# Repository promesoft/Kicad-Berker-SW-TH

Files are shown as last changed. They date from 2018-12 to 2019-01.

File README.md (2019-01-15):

Green board

# Overview
## Status - Rev A - Functional with issues
Rev A done by PCBWay

## Wemos D1 mini - section 1

Section 1 is a sensor board for a Wemos D1 mini, that is intended for installing in a Berker wall outlet (euro style). 
Section 1 has an AM2320, a relay and a power supply. Besides this it has breakout of pins A0 and D4.

## Issues

There is one issue with section 1 that should be addressed in the next revision. The board size is 2mm too big in X and Y, to fit into a Berker wall mount. 

## Errata
 - Edgecuts in Rev A is specified as 0,15mm - this should be 1mm
 - Footprint for AC-DC is wrong
 - Footprint for Q3 and Q4 is off

## Wemos D1 mini - section 2

Section 2 is similar to section 1 except it has room on the backside for a PM03 AC-DC converter. 
It is intended as a board for installing in a Berker outlet. 
Section 2 has an AM2320, a relay and a power supply. Besides this it has breakout of pins A0 and D4.

## Issues

There are two flaws with section 2 that should be addressed in the next revision: 
### Board dimensions
The corners of the board inhibits it from fitting into a Berker wall mount. 
Either the board should be 47x47mm (3mm shorter in X and Y) or the corners should be milled away with a 8mm diameter drill
### Footprint of AC-DC converter
The PM03 footprint has been flipped so it does not fit in the PCB.

## Virtual Ground Section

# 3D board view

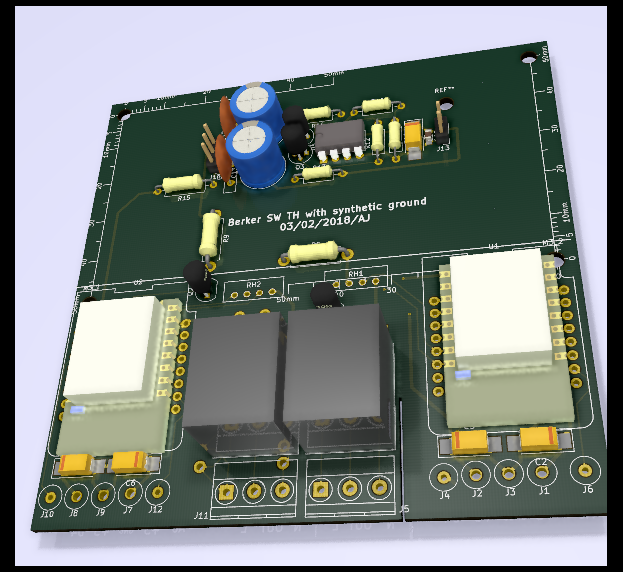
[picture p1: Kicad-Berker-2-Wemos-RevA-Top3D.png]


# Shecmatic

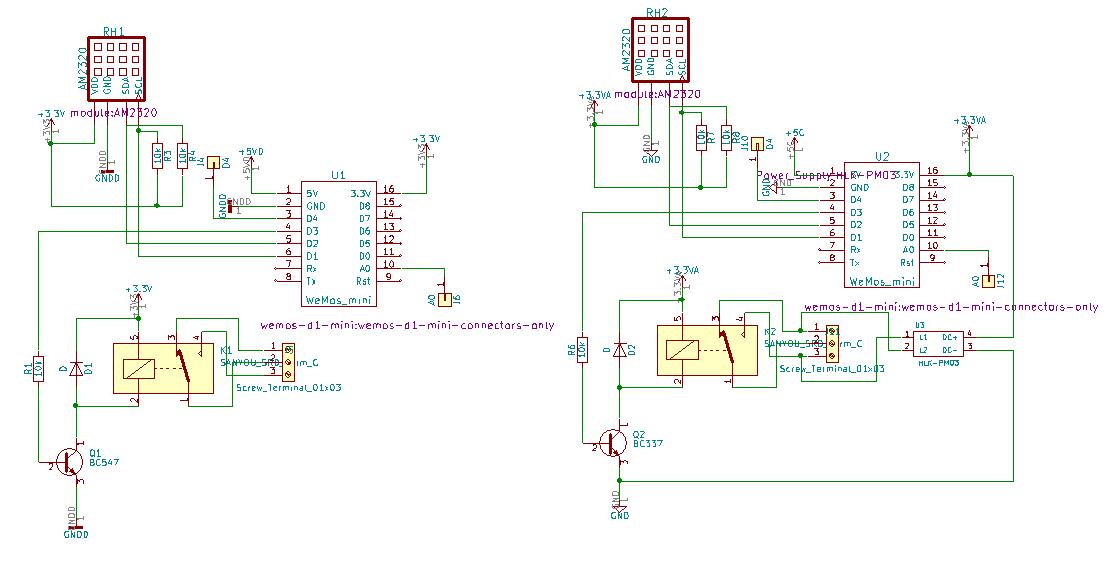
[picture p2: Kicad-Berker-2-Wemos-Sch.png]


# Section 2 
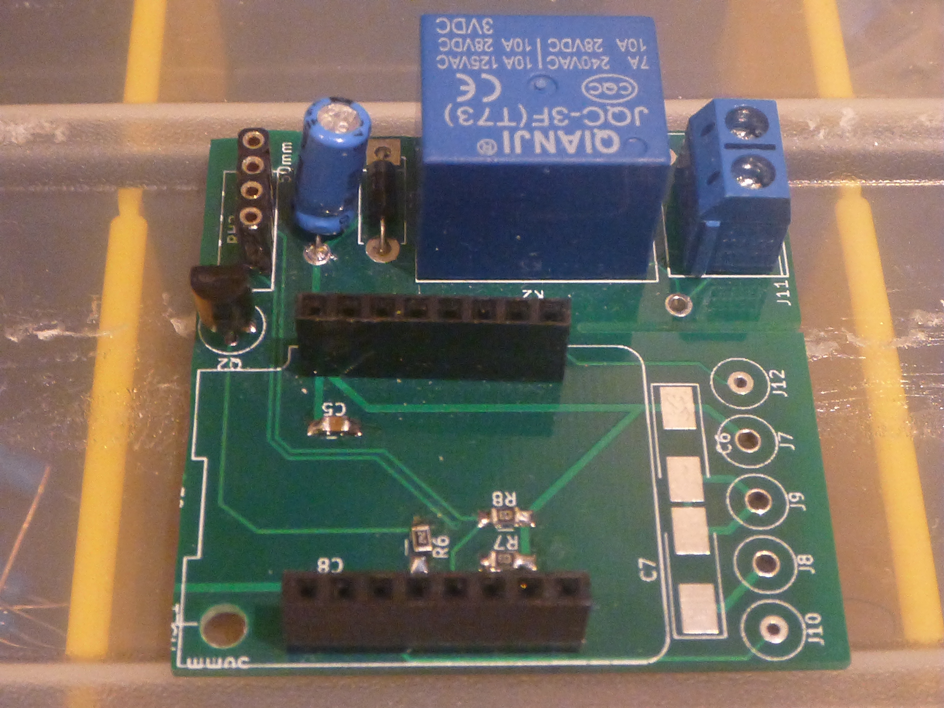
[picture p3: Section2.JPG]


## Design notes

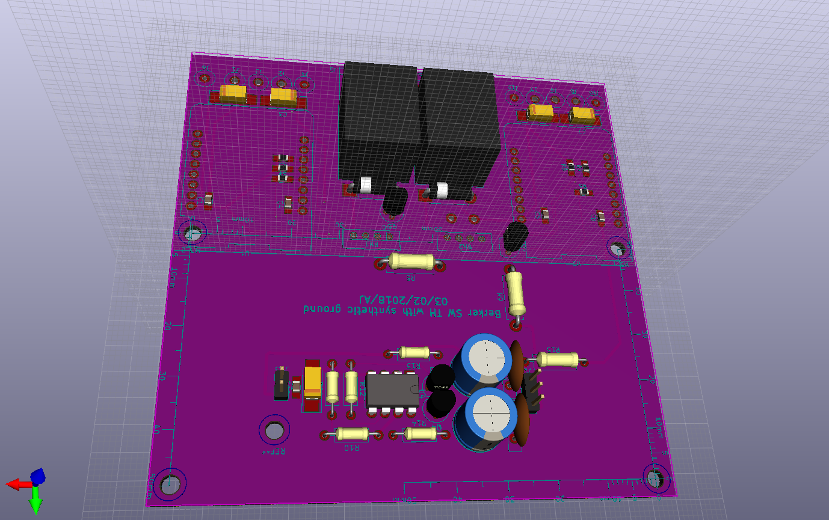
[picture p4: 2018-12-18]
Kicad-Berker-2-Wemos-3D.png

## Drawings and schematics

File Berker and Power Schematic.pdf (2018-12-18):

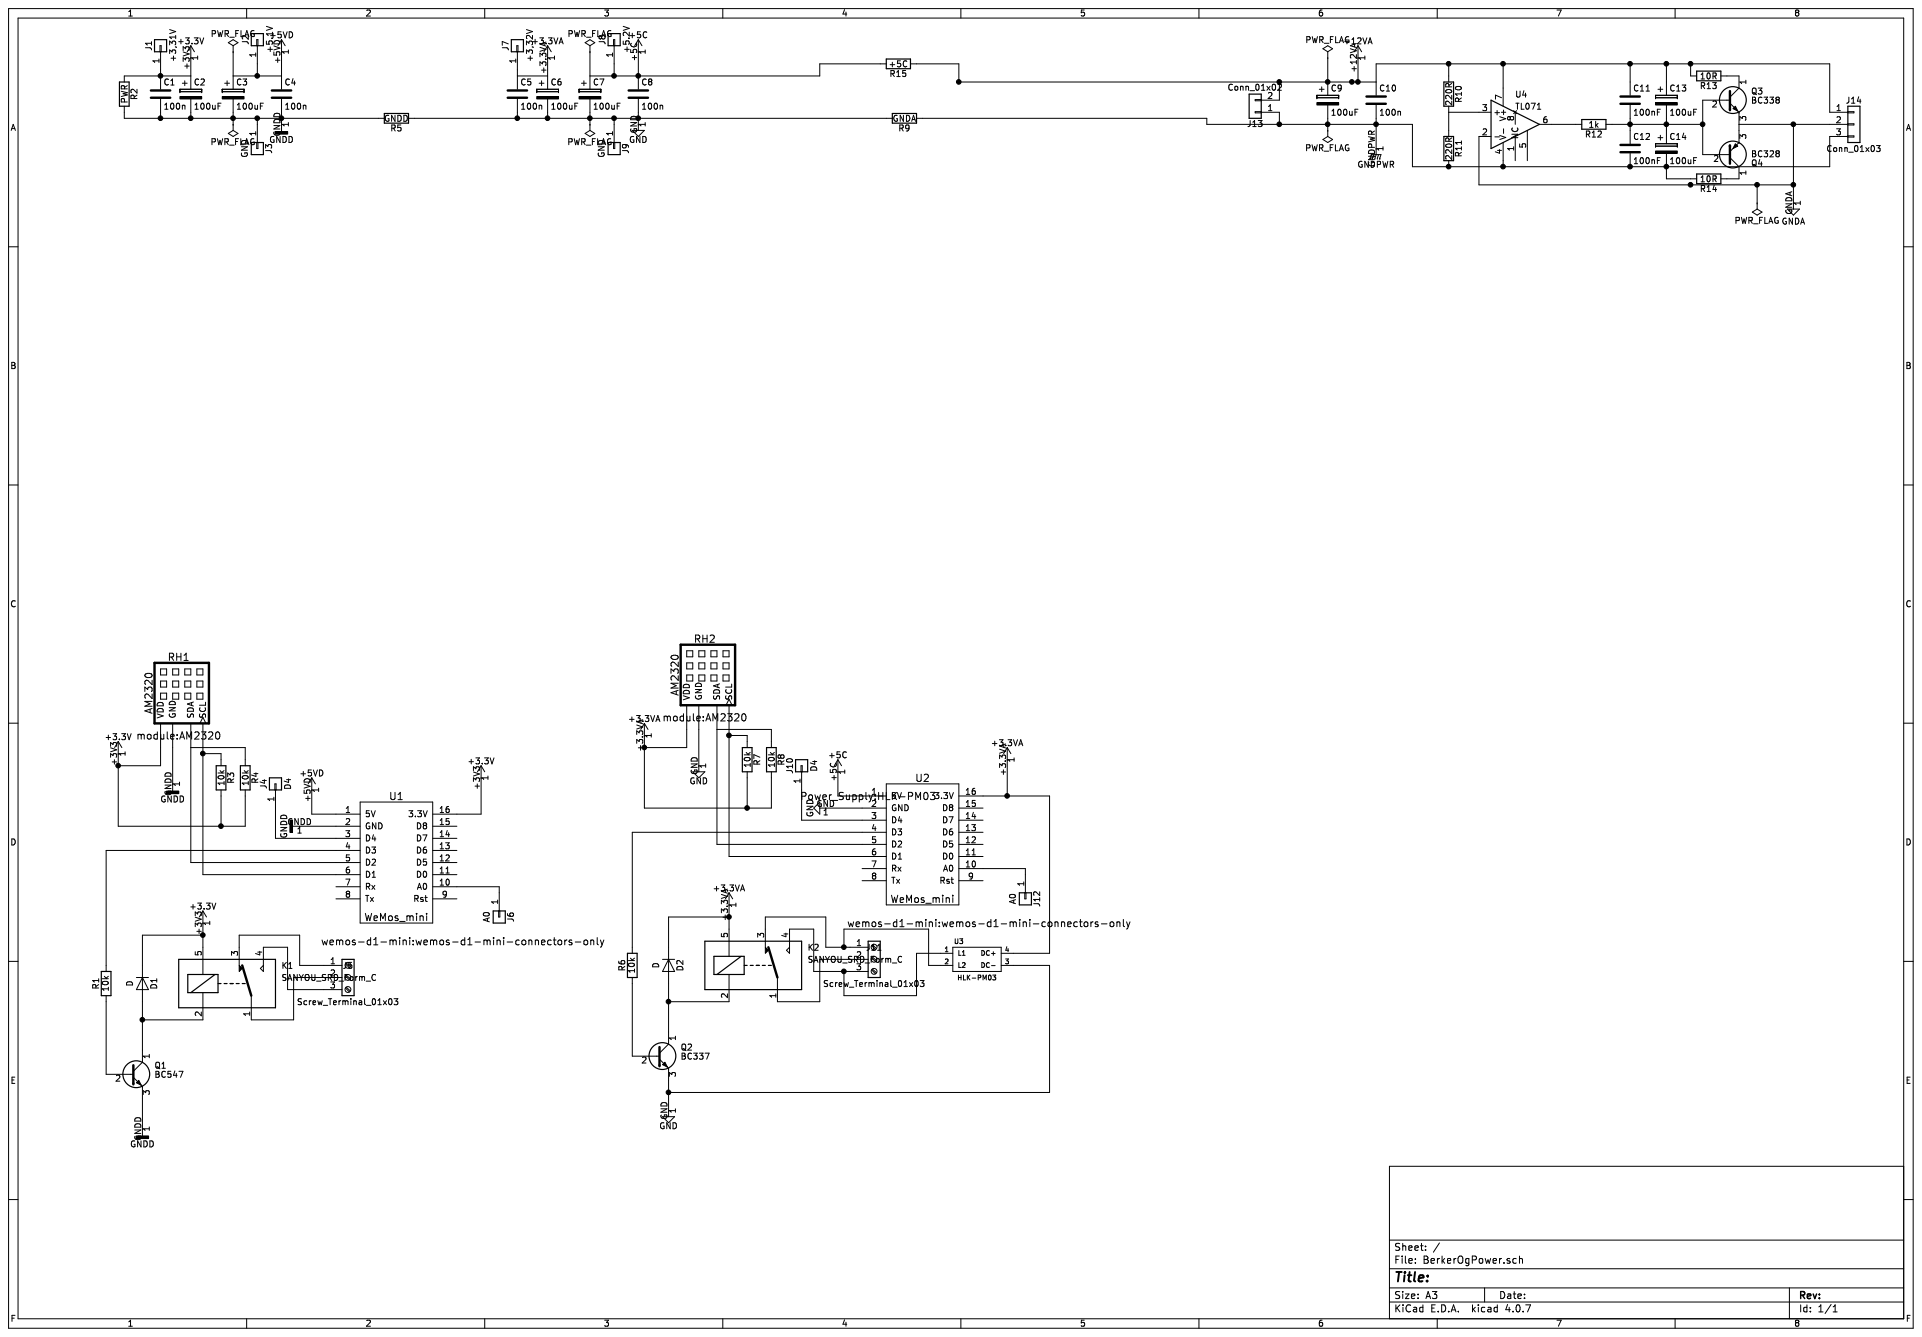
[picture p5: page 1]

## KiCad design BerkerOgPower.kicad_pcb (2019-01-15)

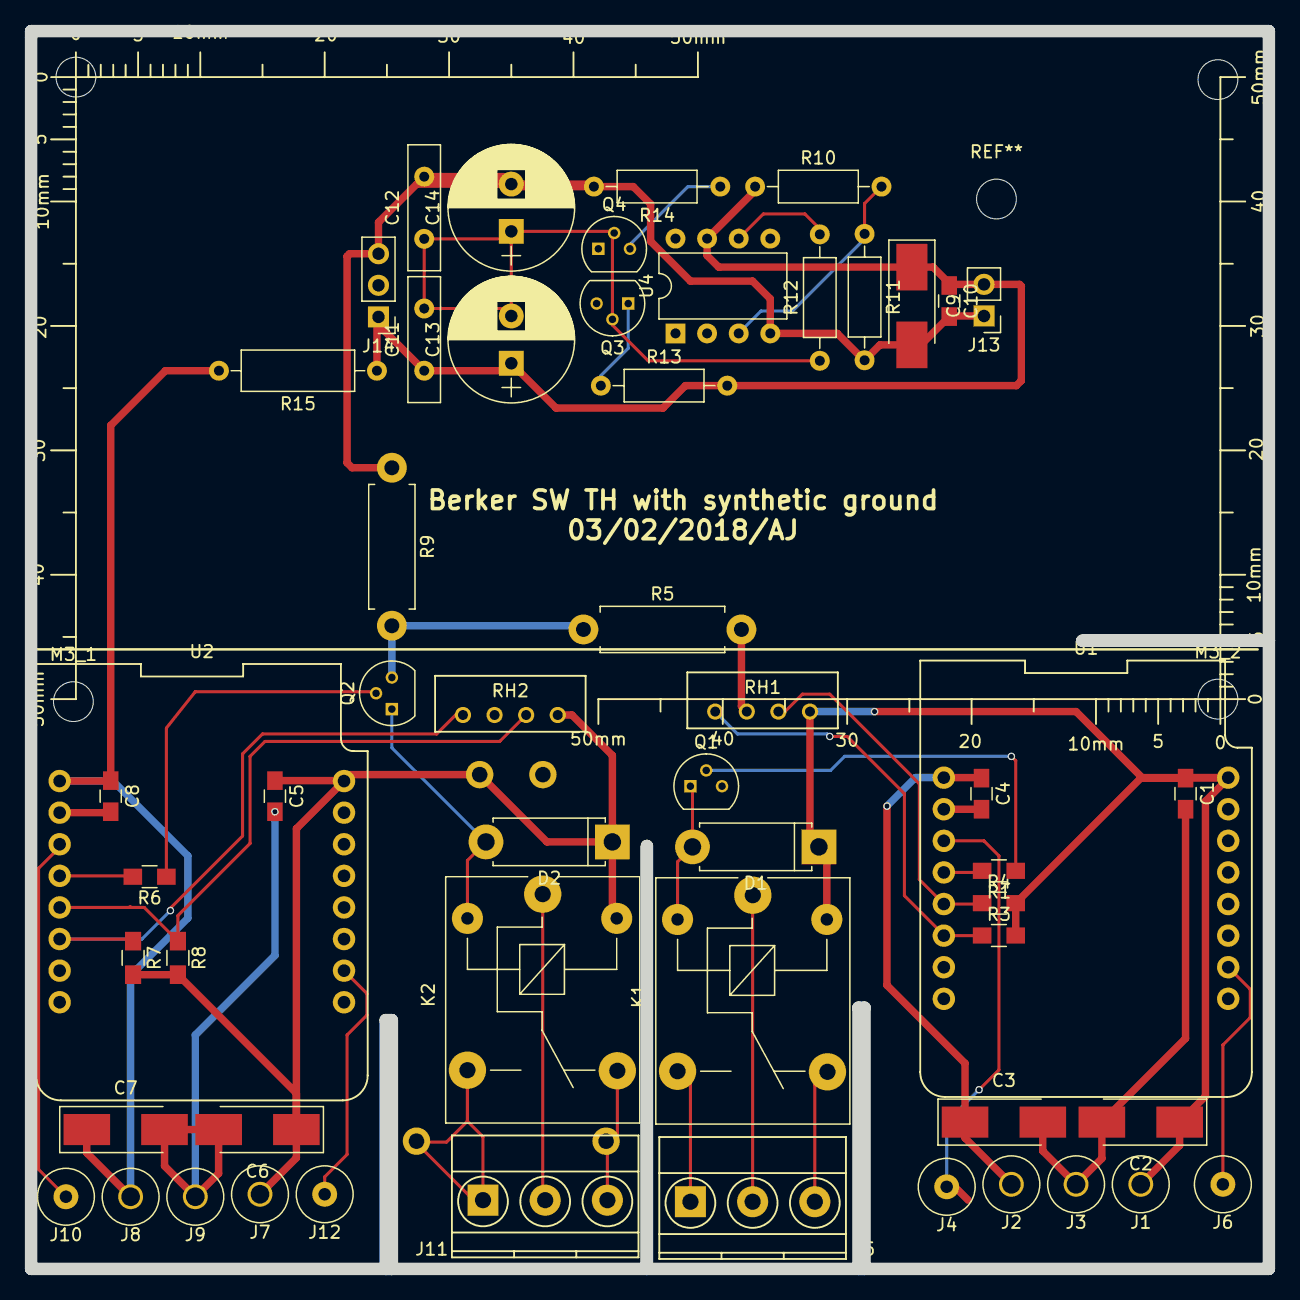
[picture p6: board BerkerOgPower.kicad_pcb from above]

Board: 2 copper layers, 99.5 x 99.5 mm, 58 parts (1 on the bottom side), 34 nets.

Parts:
C1, C4, C5, C8, C10: 100n; C_0805_HandSoldering
C2, C3, C6, C7, C9: 100uF; CP_Tantalum_Case-C_EIA-6032-28_Hand
C11, C12: 100nF; C_Disc_D10.0mm_W2.5mm_P5.00mm
C13, C14: 100uF; CP_Radial_D10.0mm_P3.80mm
D1, D2: D; D_5W_P10.16mm_Horizontal
J1: +3,31V; 1pin
J2: +5.1V; 1pin
J3, J9: GND; 1pin
J4, J10: D4; 1pin
J5, J11: Screw_Terminal_01x03; TerminalBlock_Phoenix_MKDS1.5-3pol
J6, J12: A0; 1pin
J7: +3,32V; 1pin
J8: +5.2V; 1pin
J13: Conn_01x02; Pin_Header_Straight_1x02_Pitch2.54mm
J14: Conn_01x03; Pin_Header_Straight_1x03_Pitch2.54mm
K1, K2: SANYOU_SRD_Form_C; Relay_SPDT_SANYOU_SRD_Series_Form_C
M3_1, M3_2: MountingHole_3.2mm_M3_DIN965
Q1: BC547; TO-92_Molded_Narrow
Q2: BC337; TO-92_Molded_Narrow
Q3: BC338; TO-92_Molded_Narrow
Q4: BC328; TO-92_Molded_Narrow
R1, R3, R4, R6, R7, R8: 10k; R_0805_HandSoldering
R5: GNDD; R_Axial_DIN0411_L9.9mm_D3.6mm_P12.70mm_Horizontal
R9: GNDA; R_Axial_DIN0411_L9.9mm_D3.6mm_P12.70mm_Horizontal
R10, R11: 220R; R_Axial_DIN0207_L6.3mm_D2.5mm_P10.16mm_Horizontal
R12: 1k; R_Axial_DIN0207_L6.3mm_D2.5mm_P10.16mm_Horizontal
R13, R14: 10R; R_Axial_DIN0207_L6.3mm_D2.5mm_P10.16mm_Horizontal
R15: +5C; R_Axial_DIN0309_L9.0mm_D3.2mm_P12.70mm_Horizontal
RH1, RH2: AM2320
U1, U2: WeMos_mini; wemos-d1-mini-connectors-only
U3: HLK-PM03; HLK-PM03-AJ
U4: TL071; DIP-8_W7.62mm

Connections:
+3.3VA: C5.1, C6.1, D2.1, J7.1, K2.5, R7.2, R8.2, RH2.1, U2.16, U3.4
+3V3: C1.1, C2.1, D1.1, J1.1, K1.5, R3.2, R4.2, RH1.1, U1.16
+5C: C7.1, C8.1, J8.1, R15.2, U2.1
+5VD: C3.1, C4.1, J2.1, U1.1
+12VA: C9.1, C10.1, C11.1, C13.1, J13.2, J14.1, R10.1, R13.2, R15.1, U4.7
GND: C5.2, C6.2, C7.2, C8.2, J9.1, Q2.3, R5.1, R9.2, RH2.3, U2.2, U3.3
GNDA: J14.2, Q3.3, Q4.1, U4.2
GNDD: C1.2, C2.2, C3.2, C4.2, J3.1, Q1.3, R5.2, RH1.3, U1.2
GNDPWR: C9.2, C10.2, C12.2, C14.2, J13.1, J14.3, R9.1, R11.2, R14.2, U4.4
unnamed: C11.2, C12.1, C13.2, C14.1, Q3.2, Q4.2, R12.1
unnamed: D1.2, K1.2, Q1.1
unnamed: D2.2, K2.2, Q2.1
unnamed: J4.1, U1.3
unnamed: J5.1, K1.3
unnamed: J5.2, K1.1
unnamed: J5.3, K1.4
unnamed: J6.1, U1.10
unnamed: J10.1, U2.3
unnamed: J11.1, K2.3, U3.2
unnamed: J11.2, K2.1
unnamed: J11.3, K2.4, U3.1
unnamed: J12.1, U2.10
unnamed: Q1.2, R1.1
unnamed: Q2.2, R6.1
unnamed: Q3.1, R13.1
unnamed: Q4.3, R14.1
unnamed: R1.2, U1.4
unnamed: R3.1, RH1.4, U1.6
unnamed: R4.1, RH1.2, U1.5
unnamed: R6.2, U2.4
unnamed: R7.1, RH2.4, U2.6
unnamed: R8.1, RH2.2, U2.5
unnamed: R10.2, R11.1, U4.3
unnamed: R12.2, U4.6

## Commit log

2018-12-18 Project restore
    Restored from local copy
    [BerkerOgPower.kicad_pcb, BerkerOgPower.sch]
2018-12-18 Create Kicad-Berker-2-Wemos-Sch.png
    schematic
2018-12-18 Create Kicad-Berker-2-Wemos-3D.png
    3D pict
2019-01-15 3D and edgecut
    [BerkerOgPower.kicad_pcb]
